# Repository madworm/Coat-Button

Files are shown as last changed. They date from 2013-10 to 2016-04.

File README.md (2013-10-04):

Coat-Button
===========

LAYOUT FILES: Sewable blinky button for coats.

Make sure to check all [branches!](https://github.com/madworm/Coat-Button/branches)

You will find code for this project in [this](https://github.com/madworm/ATtiny_projects/tree/master/13/Coat-Button) repository.

---

Before having PC-boards made, please make sure you know about your manufacturer's peculiarities!
Especially drill-sizes and their tolerances may vary too much and give you trouble.

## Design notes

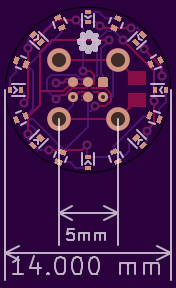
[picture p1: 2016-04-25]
14mm-WLCSP/gerber_files/PNGs/Coat-Button__mixed_purple.png

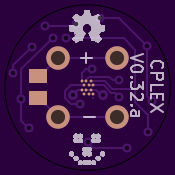
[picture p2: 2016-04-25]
14mm-WLCSP/gerber_files/PNGs/Coat-Button__back_purple.png

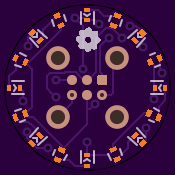
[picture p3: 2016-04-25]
14mm-WLCSP/gerber_files/PNGs/Coat-Button__front_purple.png

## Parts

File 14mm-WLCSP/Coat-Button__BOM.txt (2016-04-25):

Bill of materials:
------------------

C1		4.7µF, 0805, 10V
IC1		ATTINY20-UUR, WLCSP
LED1-8		LED, 0402
R1-R8		resistor, 0402, 4mA RMS per LED max.

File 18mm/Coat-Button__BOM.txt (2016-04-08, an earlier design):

Bill of materials:
------------------

C1		4.7µF, 0805, 10V
IC1		ATTINY13-MM, DFN10
LED1-8		LED, 0805
R1-R8		resistor, 0603, 4mA RMS per LED max.

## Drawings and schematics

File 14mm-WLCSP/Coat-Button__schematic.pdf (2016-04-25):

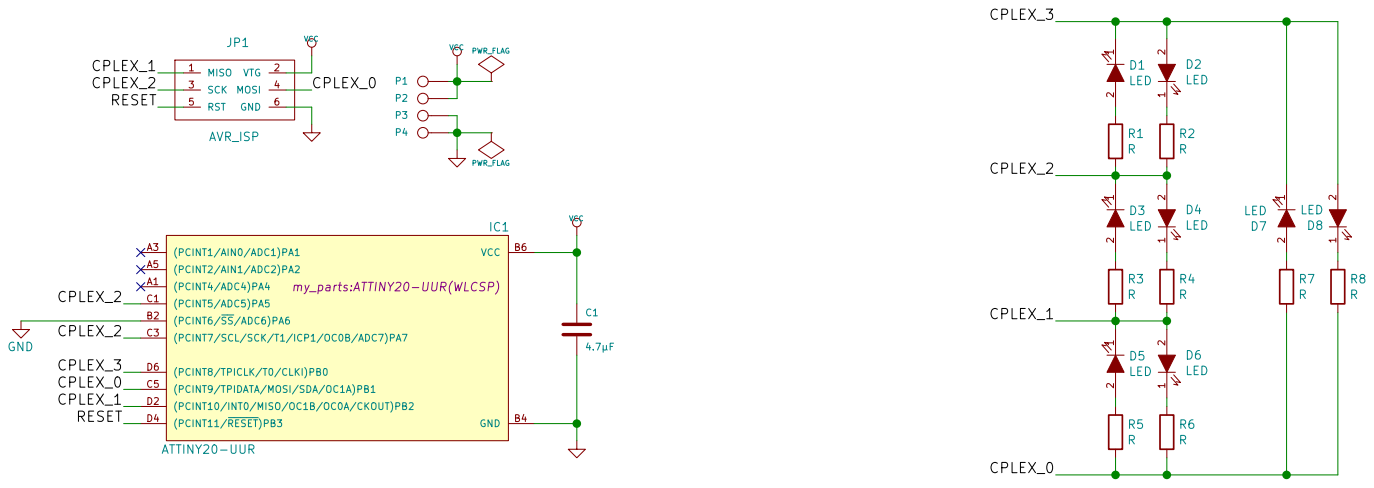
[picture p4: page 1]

Id: 1/1 Title: Coat-Button (CPLEX) File: Coat-Button.sch Sheet: / 2016 - blog.spitzenpfeil.org

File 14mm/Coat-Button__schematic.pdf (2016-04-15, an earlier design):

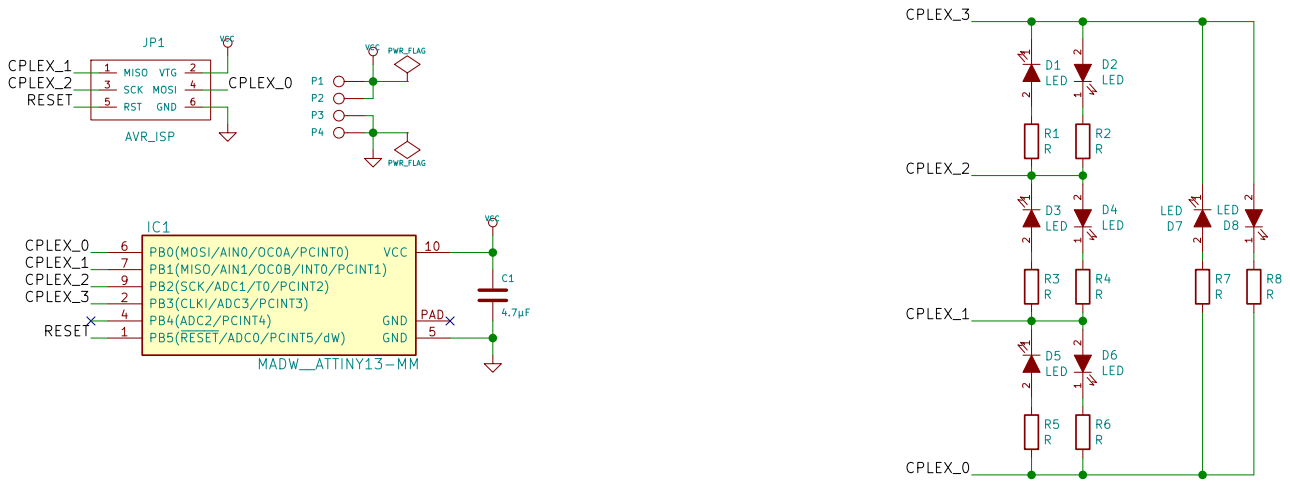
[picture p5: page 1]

Id: 1/1 Title: Coat-Button (CPLEX) File: Coat-Button.sch Sheet: / 2016 - blog.spitzenpfeil.org

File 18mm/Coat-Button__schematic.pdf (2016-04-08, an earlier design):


Id: 1/1 Title: Coat-Button (CPLEX) File: Coat-Button.sch Sheet: / 2016 - blog.spitzenpfeil.org

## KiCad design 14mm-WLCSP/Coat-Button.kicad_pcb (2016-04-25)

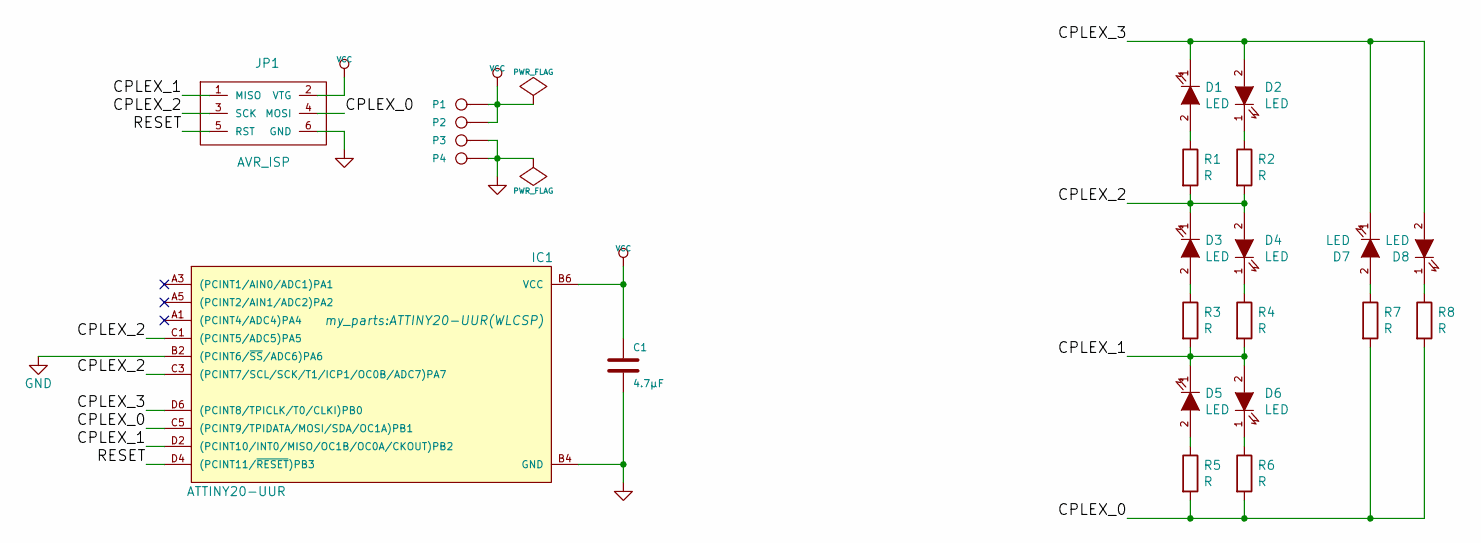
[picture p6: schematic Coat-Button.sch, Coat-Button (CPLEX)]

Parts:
C1: 4.7µF; MADW__C0805
D1, D2, D3, D4, D5, D6, D7, D8: LED; LED_0402
IC1: ATTINY20-UUR; ATTINY20-UUR(WLCSP)
JP1: AVR_ISP; DIL-3_1.27mm
P1, P2, P3, P4: CONN_1; SIL-1
R1, R2, R3, R4, R5, R6, R7, R8: R; R_0402

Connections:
/CPLEX_0: IC1.C5 ((PCINT9/TPIDATA/MOSI/SDA/OC1A)PB1), JP1.4 (MOSI), R5.2, R6.2, R7.2, R8.2
/CPLEX_1: D5.1 (K), D6.2 (A), IC1.D2 ((PCINT10/INT0/MISO/OC1B/OC0A/CKOUT)PB2), JP1.1 (MISO), R3.2, R4.2
/CPLEX_2: D3.1 (K), D4.2 (A), IC1.C1 ((PCINT5/ADC5)PA5), IC1.C3 ((PCINT7/SCL/SCK/T1/ICP1/OC0B/ADC7)PA7), JP1.3 (SCK), R1.2, R2.2
/CPLEX_3: D1.1 (K), D2.2 (A), D7.1 (K), D8.2 (A), IC1.D6 ((PCINT8/TPICLK/T0/CLKI)PB0)
/RESET: IC1.D4 ((PCINT11/~RESET~)PB3), JP1.5 (RST)
GND: C1.2, IC1.B2 ((PCINT6/~SS~/ADC6)PA6), IC1.B4 (GND), JP1.6 (GND), P3.1, P4.1
unnamed: D1.2 (A), R1.1
unnamed: D2.1 (K), R2.1
unnamed: D3.2 (A), R3.1
unnamed: D4.1 (K), R4.1
unnamed: D5.2 (A), R5.1
unnamed: D6.1 (K), R6.1
unnamed: D7.2 (A), R7.1
unnamed: D8.1 (K), R8.1
VCC: C1.1, IC1.B6 (VCC), JP1.2 (VTG), P1.1, P2.1

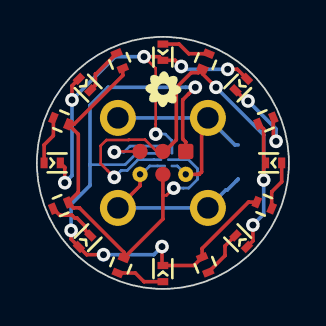
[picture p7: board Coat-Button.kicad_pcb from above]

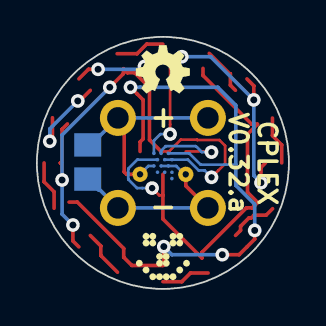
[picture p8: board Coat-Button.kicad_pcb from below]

Board: 2 copper layers, 14.0 x 14.0 mm, 26 parts (4 on the bottom side), 15 nets.

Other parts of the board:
G1: OSHW-logo_silkscreen_3mm
G2: LED_smile_silkscreen_3mm
G3: floral-shape_silkscreen_2mm

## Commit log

2013-09-14 On-board ATtiny13 wasn't doable. Not enough space.
    [Coat-Button-B_Cu.gbl, Coat-Button-B_Mask.gbs, Coat-Button-B_SilkS.gbo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]
2013-09-14 Added some stuff to the 'Driver-Board'.
    [Coat-Button.kicad_pcb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]
2013-09-14 Added mechanical dimension.
    [Coat-Button.kicad_pcb]
2013-09-15 Managed to get an ATtiny13 (DFN10) on there again ;-)
    [Coat-Button-B_Cu.gbl, Coat-Button-B_Mask.gbs, Coat-Button-B_SilkS.gbo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]
2013-09-16 Tweaks. Added solder-bridge if no micro is used.
    [Coat-Button.kicad_pcb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]
2013-09-18 Renamed stuff.
    [Coat-Button-B_Cu.gbl, Coat-Button-B_Mask.gbs, Coat-Button-B_SilkS.gbo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]
2013-09-18 Found & fixed a little pad-size inconsistency.
    [Coat-Button.kicad_pcb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]
2013-09-18 Silkscreen tweaks.
    [Coat-Button.kicad_pcb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]
2013-09-19 Updated dimensions info.
    [Coat-Button.kicad_pcb]
2013-09-19 Tweaks for viewing gerber files with gerbv.
    [Coat-Button-Cmts_User.gbr]
2013-09-19 Forgot to set REFs for silkscreen logos.
    [Coat-Button.kicad_pcb]
2013-09-19 Some silkscreen / mask tweaks on the back side.
    [Coat-Button-B_Cu.gbl, Coat-Button-B_Mask.gbs, Coat-Button-B_SilkS.gbo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]
2013-09-23 Tweaks + schematic as pdf.
    [Coat-Button.sch]
2013-09-23 Made one with dual-colour LEDs (0805). Just to see if possible.
    Had to use 0402 resitors...
    [Coat-Button-B_Cu.gbl, Coat-Button-B_Mask.gbs, Coat-Button-B_SilkS.gbo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]
2013-09-25 Moved some vias around.
    Tracks connecting to them were erroneously deleted by applying
    'Delete unconnected tracks'. Now everything is 'solid'.
    [Coat-Button-B_Cu.gbl, Coat-Button-B_Mask.gbs, Coat-Button-B_SilkS.gbo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]
2013-09-25 Added 2 SOT523 n-ch mosfets + reduced LED resistors.
    [Coat-Button-B_Cu.gbl, Coat-Button-B_Mask.gbs, Coat-Button-B_SilkS.gbo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]
2013-09-27 Tweaked some vias.
    [Coat-Button-B_Cu.gbl, Coat-Button-B_Mask.gbs, Coat-Button-B_SilkS.gbo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]
2013-10-03 Tweaked SOT523 footprint (backside) for easy drain/source bridging.
    Now the same board can be used for single/dual color or just LEDs.
    [Coat-Button-B_Cu.gbl, Coat-Button-B_Mask.gbs, Coat-Button-B_SilkS.gbo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]
2013-10-03 Tweaked the BI-LED footprints a bit. Better for normal LEDs.
    [Coat-Button-B_Cu.gbl, Coat-Button-B_Mask.gbs, Coat-Button-B_SilkS.gbo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]
2013-10-03 Added alternative 0603 R. footprints for single-color mode.
    [Coat-Button-B_Cu.gbl, Coat-Button-B_Mask.gbs, Coat-Button-B_SilkS.gbo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]
2013-10-08 Added a bit of silkscreen art.
    [Coat-Button-B_Cu.gbl, Coat-Button-B_Mask.gbs, Coat-Button-B_SilkS.gbo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]
2013-10-12 Added 3D footprints. Looks good with new 3D viewer.
    [Coat-Button.kicad_pcb]
2013-10-12 Fixed 180° rotation of 0805 LED 3D models.
    [Coat-Button.kicad_pcb]
2013-10-14 Modified SOT523 footprints to allow easier solder bridges.
    [Coat-Button-B_Cu.gbl, Coat-Button-B_Mask.gbs, Coat-Button-B_SilkS.gbo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]
2013-10-14 Tweaked changes in previous commit.
    [Coat-Button-B_Cu.gbl, Coat-Button-B_Mask.gbs, Coat-Button-B_SilkS.gbo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]
2013-10-14 Moved capacitor + tweaks.
    [Coat-Button-B_Cu.gbl, Coat-Button-B_Mask.gbs, Coat-Button-B_SilkS.gbo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]
2014-01-15 Adjustments due to pcbnew's library manager.
    [Coat-Button.kicad_pcb]
2014-07-31 Added a comment to the schematic (LED resistors).
    [Coat-Button.sch]
2014-07-31 Added simplified BOM file.
2014-08-21 Added 'Coat-Button__QSG' (quick start guide).
2016-04-07 Getting started with charlieplexing.
    [Coat-Button-B_Cu.gbl, Coat-Button-B_Mask.gbs, Coat-Button-B_SilkS.gbo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]
2016-04-08 Might be ready for ordering a prototype from oshpark.
    [Coat-Button-B.Cu.gbl, Coat-Button-B.Mask.gbs, Coat-Button-B.Paste.gbp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]
2016-04-15 Added '14mm' board.
    [Coat-Button-B.Cu.gbl, Coat-Button-B.Mask.gbs, Coat-Button-B.Paste.gbp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]
2016-04-25 Added '14mm-WLCSP' (ATtiny20-UUR).
    [Coat-Button-B.Cu.gbl, Coat-Button-B.Mask.gbs, Coat-Button-B.Paste.gbp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]
